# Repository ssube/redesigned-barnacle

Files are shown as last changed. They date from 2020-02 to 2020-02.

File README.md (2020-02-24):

# Redesigned Barnacle

Prometheus environment sensor with printed case, optional display
with graph, and related utilities.

Cross-platform for MicroPython on ESP32-POE and CircuitPython on M4
Express.

## Contents

- [Redesigned Barnacle](#redesigned-barnacle)
  - [Contents](#contents)
  - [TODO](#todo)
  - [Device Setup](#device-setup)
  - [Metrics](#metrics)
    - [Metric Names](#metric-names)
    - [Metric Labels](#metric-labels)
  - [Hardware](#hardware)
    - [Supported Boards](#supported-boards)
    - [Supported Sensors](#supported-sensors)
    - [ESP32-POE Case](#esp32-poe-case)
  - [Utilities](#utilities)

## TODO

- hardware:
  - esp32-poe case
    - waterproof shell
  - m4 express case
- metrics:
  - power:
    - battery level
    - solar source
- ota update
  - endpoint authentication
  - app & config update (probably not libs)

## Device Setup

1. configure:
    1. copy and customize `./config/000-template.yml` for this room
       1. `label_location`
       2. `net_ip`
    2. `cp ./config/${IP}-${ROOM}.yml /media/${USER}/${CARD}/config.yml`
    3. `rsync -avhL ./image/app /media/${USER}/${CARD}/app`
    4. `rsync -avhL ./image/lib /media/${USER}/${CARD}/lib`
2. connect:
    1. SD card in board
    2. ethernet to board
        - ensure device **DOES NOT** power on (no PoE)
    3. sensor module to board
    4. USB power to board
    5. `ampy -p /dev/ttyUSB0 -b 115200 put ./image/boot.py /boot.py`
    6. reboot and test
3. assemble:
    1. board in case
    2. sensor ribbon cable to board
    3. board case cover
    4. sensor module cover
4. deploy somewhere
    1. ensure power and LAN lights are on
    1. ensure `http://x.y.z.${IP}:8080/metrics` is active
    1. debug over USB port

## Metrics

Metrics are published at a Prometheus endpoint, typically `http://device:8080/metrics`.

Some help text is included with each metric, and multiple reading may be present with
different labels. For example:

```none
# HELP prometheus_express_system_cpu_frequency system CPU frequency
# TYPE prometheus_express_system_cpu_frequency gauge
prometheus_express_system_cpu_frequency 160000000
# HELP prometheus_express_system_memory_alloc allocated system memory
# TYPE prometheus_express_system_memory_alloc gauge
prometheus_express_system_memory_alloc 118992
# HELP prometheus_express_system_heartbeat system heartbeat counter
# TYPE prometheus_express_system_heartbeat counter
prometheus_express_system_heartbeat 6567
# HELP prometheus_express_system_memory_free free system memory
# TYPE prometheus_express_system_memory_free gauge
prometheus_express_system_memory_free 38576
# HELP prometheus_express_sensor_humidity humidity data from the sensors
# TYPE prometheus_express_sensor_humidity gauge
prometheus_express_sensor_humidity{location="None",sensor="None"} 0
prometheus_express_sensor_humidity{location="sensor-location",sensor="bme280"} 20.75245
# HELP prometheus_express_sensor_moisture moisture data from the sensors
# TYPE prometheus_express_sensor_moisture gauge
prometheus_express_sensor_moisture{location="None",sensor="None"} 0
# HELP prometheus_express_sensor_temperature temperature data from the sensors
# TYPE prometheus_express_sensor_temperature gauge
prometheus_express_sensor_temperature{location="None",sensor="None"} 0
prometheus_express_sensor_temperature{location="sensor-location",sensor="esp32"} 50.0
prometheus_express_sensor_temperature{location="sensor-location",sensor="bme280"} 17.93268
```

### Metric Names

- `prometheus_express_`
  - `sensor_`
    - `prometheus_express_sensor_humidity`: relative humidity
    - `prometheus_express_sensor_moisture`: soil moisture level (capacitive or resistive)
    - `prometheus_express_sensor_temperature`: temperature reading
  - `system_`
    - `prometheus_express_system_cpu_frequency`: system CPU frequency
    - `prometheus_express_system_heartbeat`: system heartbeat
    - `prometheus_express_system_memory_alloc`: allocated (used) memory
    - `prometheus_express_system_memory_free`: free memory

### Metric Labels

- `location`: present on most `_sensor` metrics, identifies the location of the sensor module, from `config['label_location']`
- `sensor`: present on most `_sensor` metrics, identifies the hardware source within the sensor module

## Hardware

### Supported Boards

- Olimex:
  - ESP32-POE: https://www.olimex.com/Products/IoT/ESP32/ESP32-POE/open-source-hardware
- Adafruit Feather
  - M4 Express: https://www.adafruit.com/product/3857
  - **TODO:** M0 Express

### Supported Sensors

- Adafruit Stemma soil moisture: https://www.adafruit.com/product/4026
- most BME280 environment sensors:
  - Adafruit (1x, $20): https://www.adafruit.com/product/2652
  - KeeYees (3x, $13): https://www.amazon.com/gp/product/B07KYJNFMD
  - Onyehn (4x, $17): https://www.amazon.com/gp/product/B07KR24P6P
- most SSD1306 displays (OLED):
  - Adafruit 128x64 white (1x, $20): https://www.adafruit.com/product/938
  - Adafruit 128x32 white (1x, $18): https://www.adafruit.com/product/931
  - Makerfocus 128x32 blue (2x, $11): https://www.amazon.com/gp/product/B0761LV1SD
  - Geekcreit 128x64 blue w/ yellow header (1x, $6): https://www.banggood.com/0_96-Inch-4Pin-Blue-Yellow-IIC-I2C-OLED-Display-Module-p-969144.html

### ESP32-POE Case

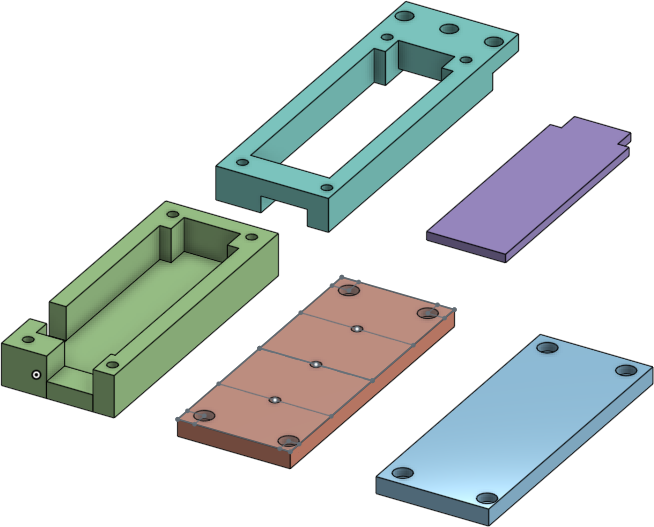
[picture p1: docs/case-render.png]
CAD render of ESP32 case components


- Onshape: https://cad.onshape.com/documents/d76ca4bd744f4af4d9935e57/w/6fa2ca68aaf1e703b4e8927f/e/7e2e7f1d76f01bc50541d834

Parts:

- base:
  - USB & RJ45 gap
  - RJ45 gap only
- mid:
  - M3 mount
  - rack mount
  - flat wall (normal)
- lid:
  - M3 mount (x3)
  - full (closed)
- spacer:
  - full
  - fork

## Utilities

- buffer
  - circular buffer with interpolated supersampling
- compat
  - platform detection
- eth
  - cross-platform connection status check
  - connection helper for static IP/DHCP
- graph
  - single bar graph
  - smoothed sparkline
- i2c
  - CircuitPython-compatible I2C bus with `try_lock`/`unlock` for MicroPython
  - bus scan/device enumerate helper
- math
  - temperature conversion
  - scale & clamp helper
  - CPython-compatible `ticks_diff`/`ticks_ms`
- mock (CPython-compatible)
  - framebuffer
  - I2C bus
  - network
- ntp
  - NTP client
  - ISO-8601 date format

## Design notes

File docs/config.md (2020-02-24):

# Config

This document describes the config file format and keys.

To configure each device, make a copy of [the config template](../config/000-template.yml)
and place it on root of the SD card.

## Contents

- [Config](#config)
  - [Contents](#contents)
  - [Keys](#keys)
    - [Display Keys](#display-keys)
    - [Image Keys](#image-keys)
    - [Label Keys](#label-keys)
    - [Net Keys](#net-keys)
    - [Sensor Keys](#sensor-keys)
    - [Server Keys](#server-keys)
    - [Stemma Keys](#stemma-keys)
  - [Syntax](#syntax)
    - [Supported Syntax](#supported-syntax)
    - [Syntax TODO](#syntax-todo)

## Keys

### Display Keys

- `display_active`
  - boolean
  - enable the display
  - note: running a 128x32 display requires some additional memory and ~50mA more power
- `display_height`
  - integer
  - display geometry, pixels on Y axis
- `display_width`
  - integer
  - display geometry, pixels on X axis

### Image Keys

- `image_name`
  - string
  - app image to chain load, filename in [`/card/app`](../image/app)

### Label Keys

- `label_location`

### Net Keys

- `net_dns`
  - string
  - IP address of the network's DNS server
- `net_gw`
  - string
  - IP address of the network's gateway
- `net_ip`
  - string
  - static IP for this device
  - omit this key to use DHCP
- `net_mask`
  - string
  - IP mash for the network subnet

### Sensor Keys

- `sensor_interval`
  - integer
  - sensor sampling interval for background timer, in milliseconds

### Server Keys

- `server_port`
  - integer
  - port on which HTTP server will listen

### Stemma Keys

- `stemma_active`
  - boolean
  - enable Stemma seesaw sensor
  - note: requires some additional memory

## Syntax

The config file uses a `.yml` extension and limited YAML syntax, implemented in [`redesigned_barnacle.config`](../redesigned_barnacle/config.py).

### Supported Syntax

- `key: value` pairs
- `# comments` and empty lines
- boolean values
- float values
- integer values
- string values (quoted or unquoted)

### Syntax TODO

- dicts
- lists
- multiline strings
- signed numbers

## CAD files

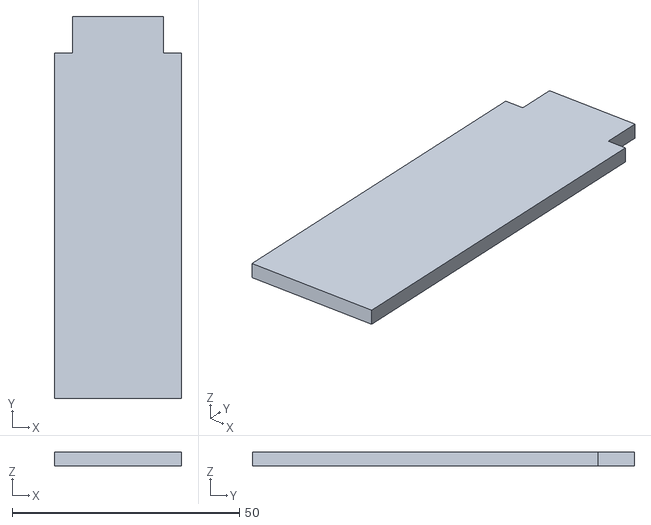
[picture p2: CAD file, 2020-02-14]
models/esp32-poe/spacer-full.stl
28.0 x 84.0 x 3.00

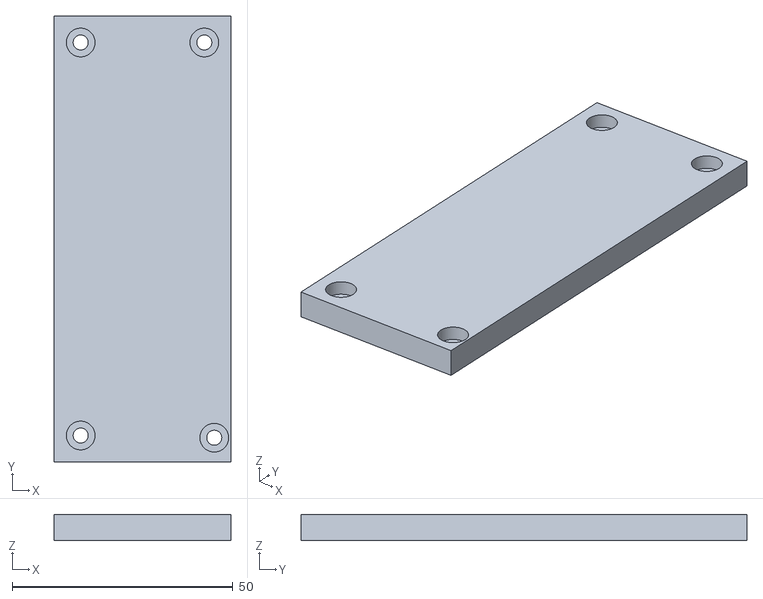
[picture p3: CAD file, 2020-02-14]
models/esp32-poe/lid-full.stl
40.0 x 101.0 x 6.00

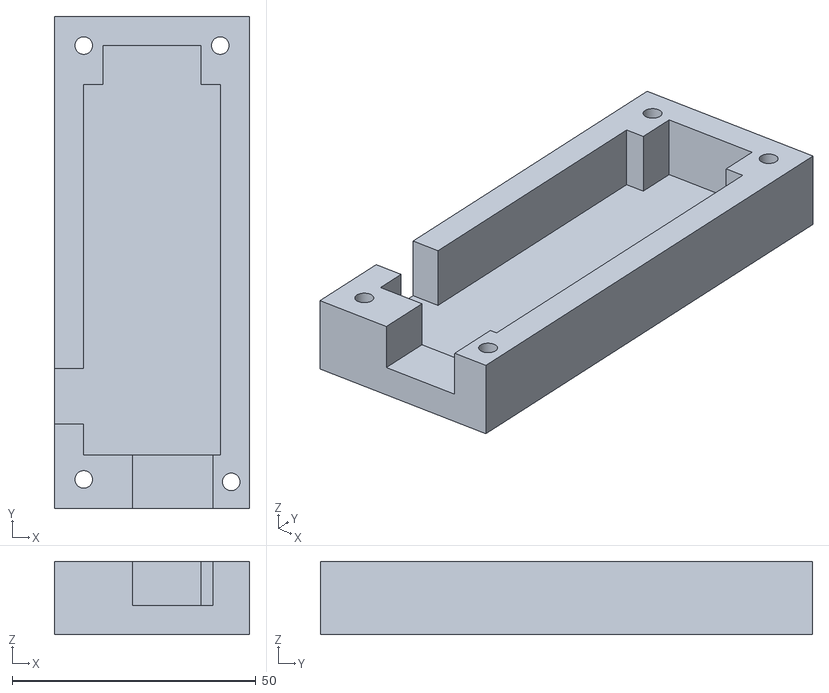
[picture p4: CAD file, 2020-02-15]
models/esp32-poe/base-usb.stl
40.0 x 101.0 x 15.0

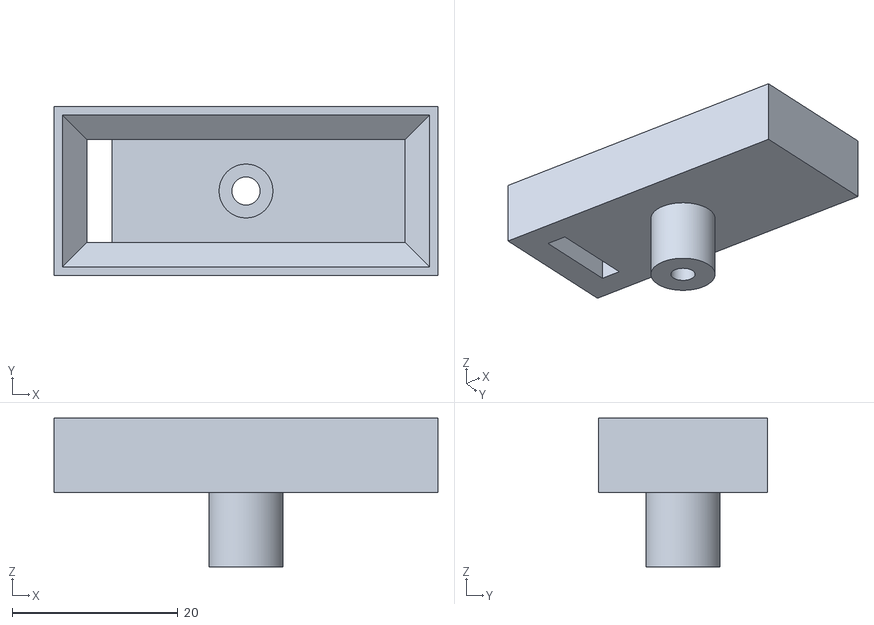
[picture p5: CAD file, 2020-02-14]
models/sensor/ssd1306-makerfocus.stl
46.4 x 20.4 x 18.0

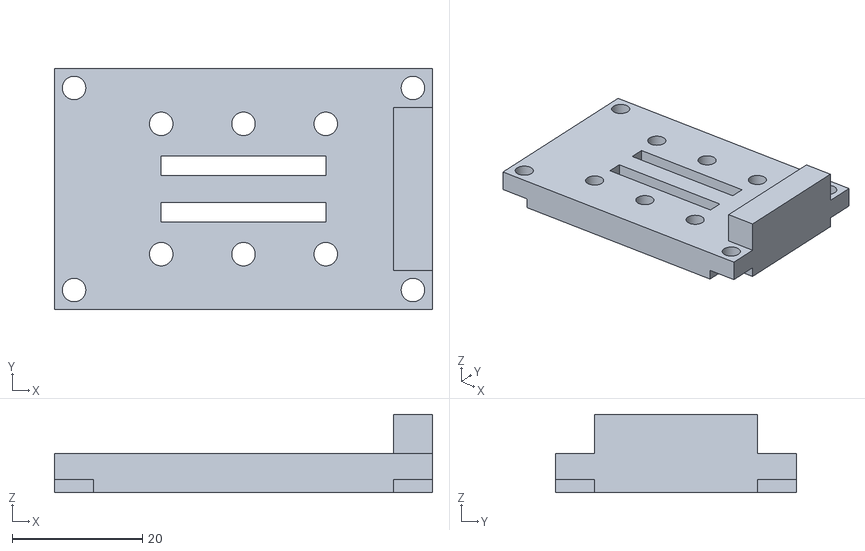
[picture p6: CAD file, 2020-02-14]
models/uext-i2c/lid-mount.stl
58.0 x 37.0 x 12.0

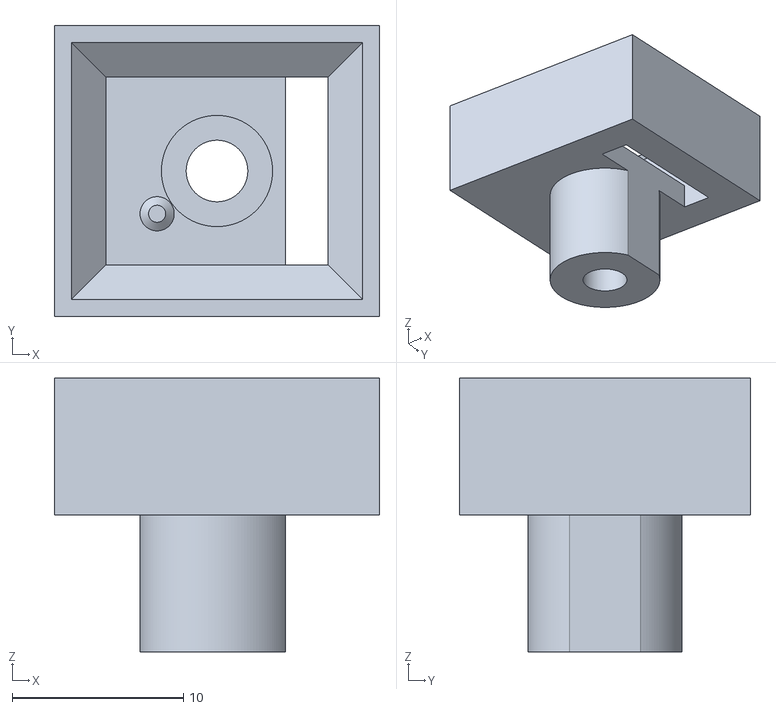
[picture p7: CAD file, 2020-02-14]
models/sensor/bme280-onyehn.stl
19.0 x 17.0 x 16.0

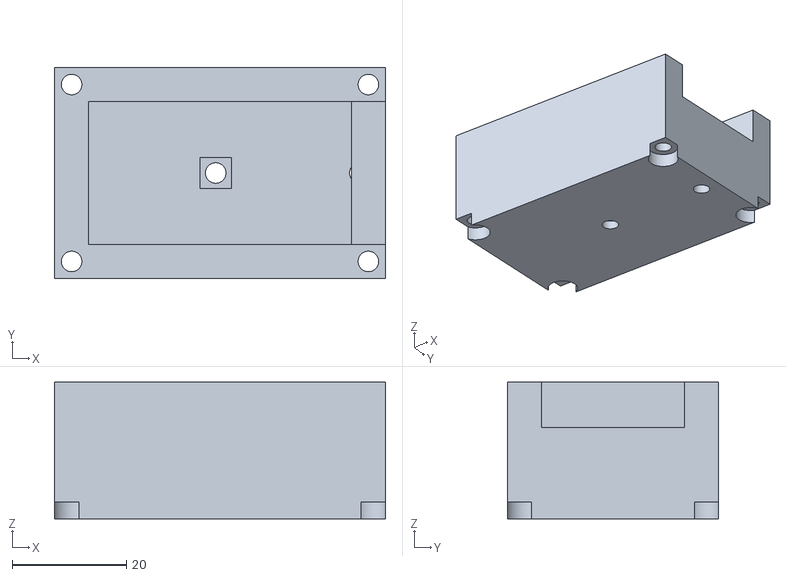
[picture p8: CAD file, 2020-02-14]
models/uext-i2c/base.stl
58.0 x 37.0 x 24.0

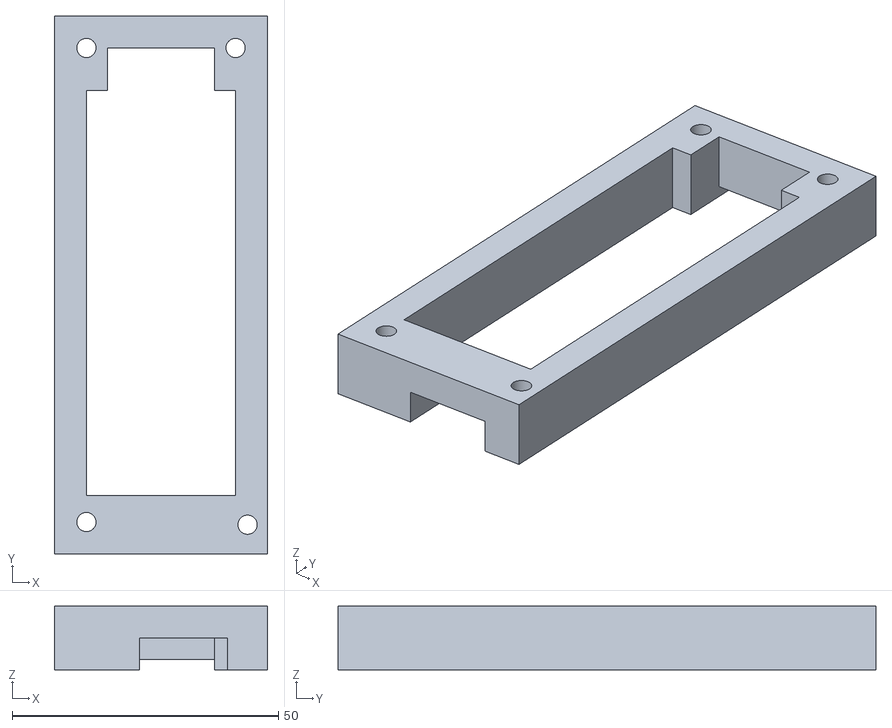
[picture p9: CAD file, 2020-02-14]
models/esp32-poe/mid-poe.stl
40.0 x 101.0 x 12.0

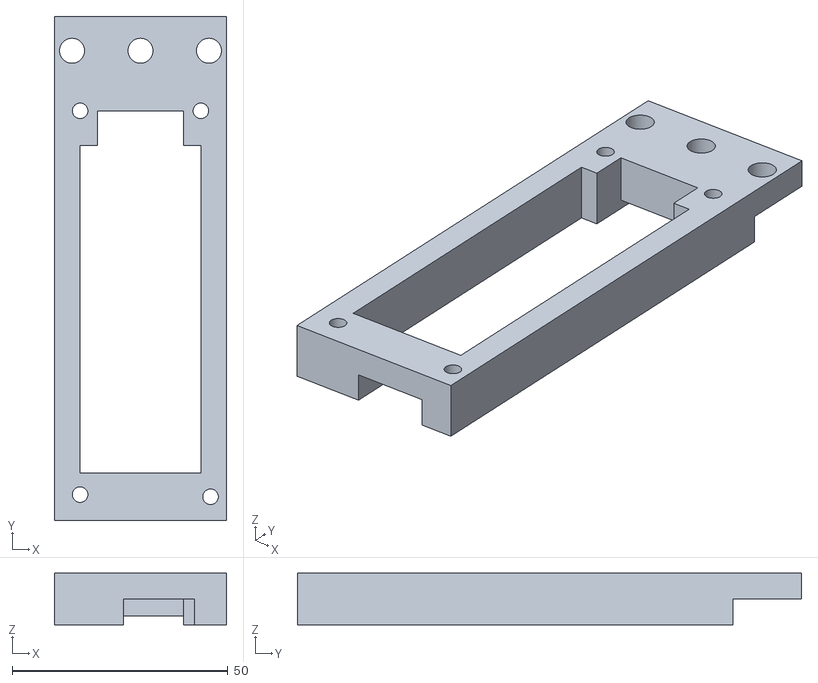
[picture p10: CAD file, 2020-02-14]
models/esp32-poe/mid-rack.stl
40.0 x 116.9 x 12.0

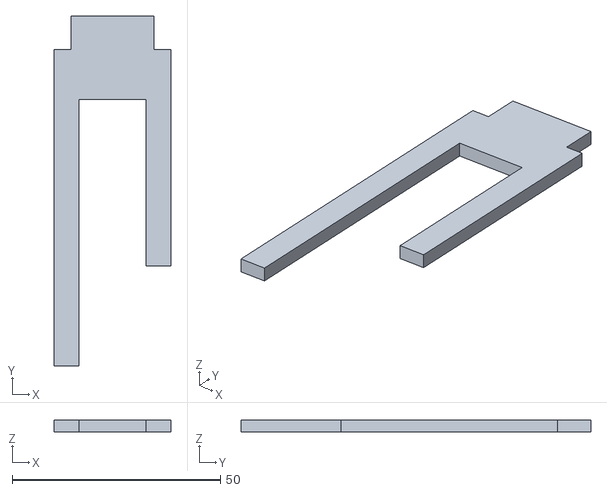
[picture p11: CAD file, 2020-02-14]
models/esp32-poe/spacer-fork.stl
28.0 x 84.0 x 3.00

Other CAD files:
models/esp32-poe/base-supports.stl
models/esp32-poe/base-poe.stl
models/esp32-poe/lid-mount.stl

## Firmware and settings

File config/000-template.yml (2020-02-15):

# this is a template config file
# limited YAML syntax is supported

display_active: True
display_height: 32
display_width: 128

image_name: esp32_poe

label_location: sensor-location

# omit net_ip to use DHCP setup
net_ip: x.y.z.w
net_mask: 255.255.255.0
net_gw: x.y.z.1
net_dns: x.y.z.1

sensor_interval: 5000

server_port: 8080

stemma_active: True
stemma_address: 54

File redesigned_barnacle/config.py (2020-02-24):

import os

BOOLEAN_TRUES = [
    'y', 'Y',
    'yes', 'Yes', 'YES',
    'true', 'True', 'TRUE',
    'on', 'On', 'ON'
]

BOOLEAN_FALSES = [
    'n', 'N',
    'no', 'No', 'NO',
    'false', 'False', 'FALSE',
    'off', 'Off', 'OFF'
]


def is_numeric(c):
    return (c >= '0' and c <= '9')


def is_decimal(c):
    return c == '.' or is_numeric(c)


def is_float(s):
    return s.count('.') <= 1 and str_all(s, is_decimal)


def is_integer(s):
    return str_all(s, is_numeric)


def str_all(s, fn):
    return all([fn(c) for c in s])


def convert_value(value):
    if value == '~':
        return None
    if value in BOOLEAN_FALSES:
        return False
    elif value in BOOLEAN_TRUES:
        return True
    elif is_integer(value):
        return int(value)
    elif is_float(value):
        return float(value)
    elif value[0] == '"':
        return value.strip('"')
    else:
        return value


def load_config(path, name):
    files = os.listdir(path)
    if not name in files:
        raise Exception('config file missing')

    config = parse_file('{}/{}'.format(path, name))
    print('Config: {}'.format(config))

    return config


def parse_file(name, open=open):
    with open(name, 'r') as source:
        return parse_str(source.readlines())


def parse_str(lines):
    data = {}
    for rline in lines:
        line = rline.strip()
        if len(line) == 0 or line[0] == '#':
            continue

        parts = line.split(':')
        if len(parts) < 2:
            continue

        key = parts[0].strip()
        value = ''.join(parts[1:]).strip()
        if len(value) == 0:
            continue

        data[key] = convert_value(value)

    return data

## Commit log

2020-02-09 fix(ntp): make ntp_fetch work on x86
    [compat.py, ntp.py]
2020-02-09 fix(compat): fix platforms without enum
    [compat.py]
2020-02-09 fix(eth): use eth_connected for compatibility
    [eth.py]
2020-02-09 feat(unit): add clamping scale helper
2020-02-10 lint(eth): remove prints from eth_check
2020-02-12 fix(graph): take existing buffer as param rather than creating a new one
    [graph.py]
2020-02-12 fix(tests): cover clamp
2020-02-14 feat(case): add esp32-poe case
    [esp32-v3-base-poe.stl, esp32-v3-base-supports.stl, esp32-v3-base-usb.stl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]
2020-02-14 feat(image): add chain bootloader and esp32 image
2020-02-15 fix(image): default moisture reading to 0
    [esp32_poe.py]
2020-02-15 remove versions from case model filenames
    [esp32-base-poe.stl, esp32-base-supports.stl, esp32-base-usb.stl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]
2020-02-15 fix(case): increase vertical space around USB port
    [esp32-base-usb.stl]
2020-02-15 lint(case): sort case models
    [base-poe.stl, base-supports.stl, base-usb.stl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]
2020-02-15 fix(docs): add hardware, case, and assembly instructions to readme
2020-02-15 feat(card): add drivers
2020-02-15 fix(docs): instructions for configuring card, case render
2020-02-18 lint: sort folders better
    [base-poe.stl, base-supports.stl, base-usb.stl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]
2020-02-19 feat(pcbs): add uext-to-i2c board designs
    [uext-molex-v2.fz, uext-molex.fz]
2020-02-24 update: bus-device lib
2020-02-24 fix(image): link this lib as card driver
